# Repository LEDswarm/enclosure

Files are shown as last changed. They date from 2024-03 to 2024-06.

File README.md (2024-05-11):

# `ledswarm_enclosure`

A custom 3D-printed enclosure for LEDswarm controllers, made to be printed out of resin in SLA printers.

This fulfills a similar role as the original bottle blanks used to enclose the electronics of Ghoust controllers, but the design has evolved into a curved transparent enclosure which supports mounting circuit boards and diffusor pipes onto a solid plastic case, holding everything firmly in place, especially regarding the USB-C board-to-board connection between the mainboard and the LED board.

## Features

- Lengthwise PCB slot for a mainboard with board edge (straddle mount) USB-C plug
- Water-tight sealing using flanges with o-rings
- Top surface within the diffusor flange to mount the LED peripheral board with M1.7 screws
- Ceiling projection using a plano-convex lens which is integrated into the top cover

## Links

* (Kameralinsen-mit-stereolithografie-herstellen)[https://formlabs.com/de/blog/kameralinsen-mit-stereolithografie-herstellen/]

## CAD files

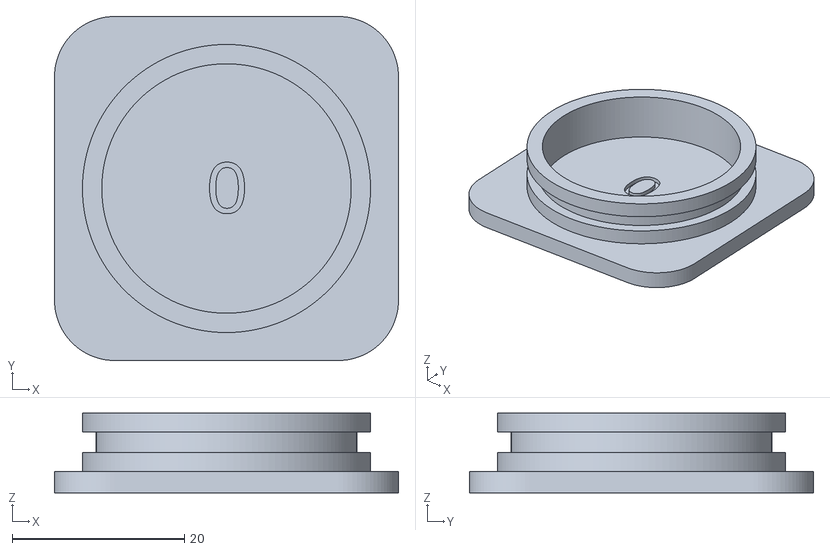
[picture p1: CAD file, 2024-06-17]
o_ring_tester_0.stl
40.0 x 40.0 x 9.25

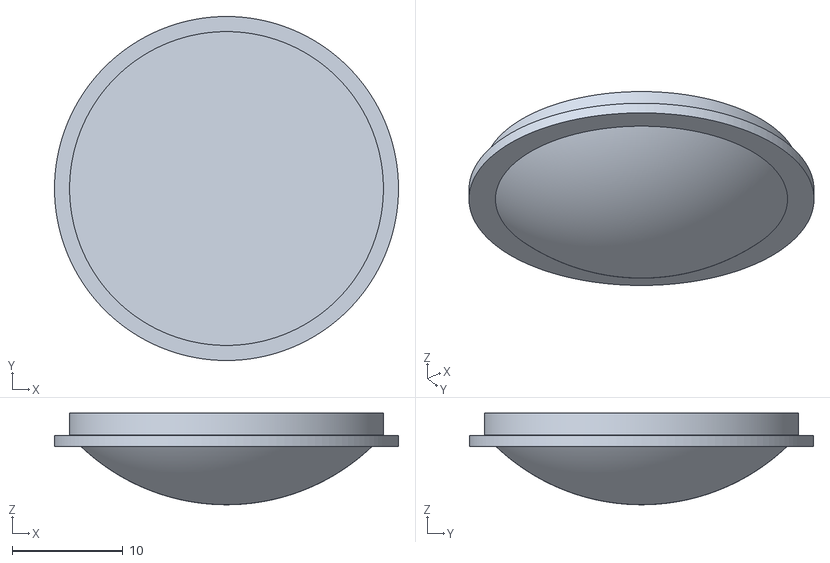
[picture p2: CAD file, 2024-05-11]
stl/top_lens_v1.stl
31.0 x 31.0 x 8.25

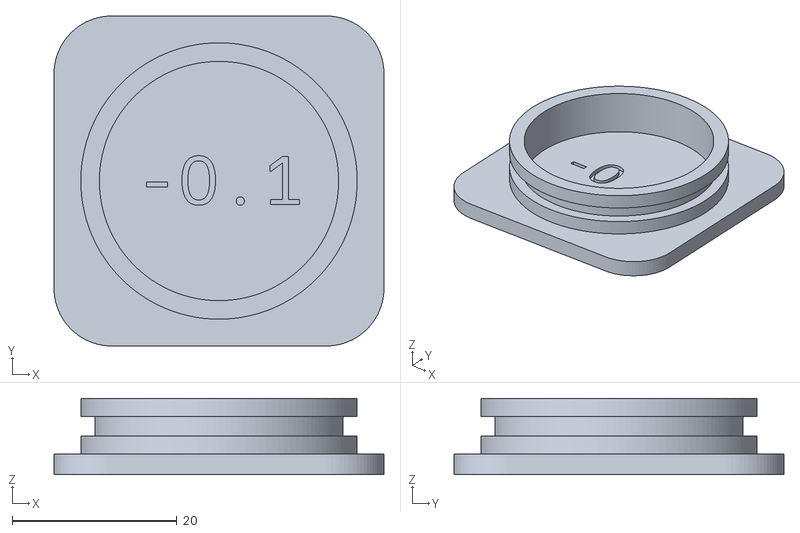
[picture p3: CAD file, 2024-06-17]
o_ring_tester_minus_0_1.stl
40.0 x 40.0 x 9.25

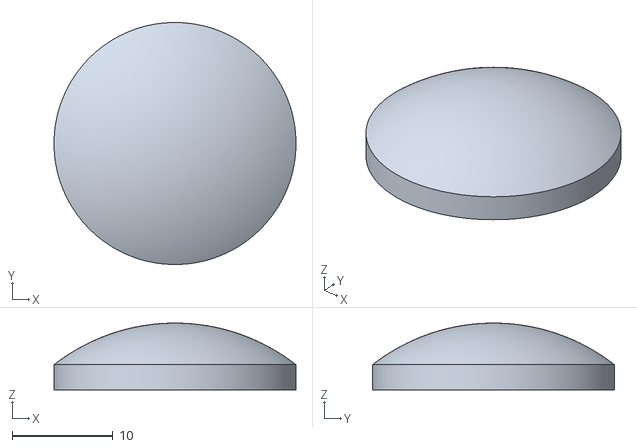
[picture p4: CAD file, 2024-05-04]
lens24mm_2_5.stl
24.0 x 24.0 x 6.63

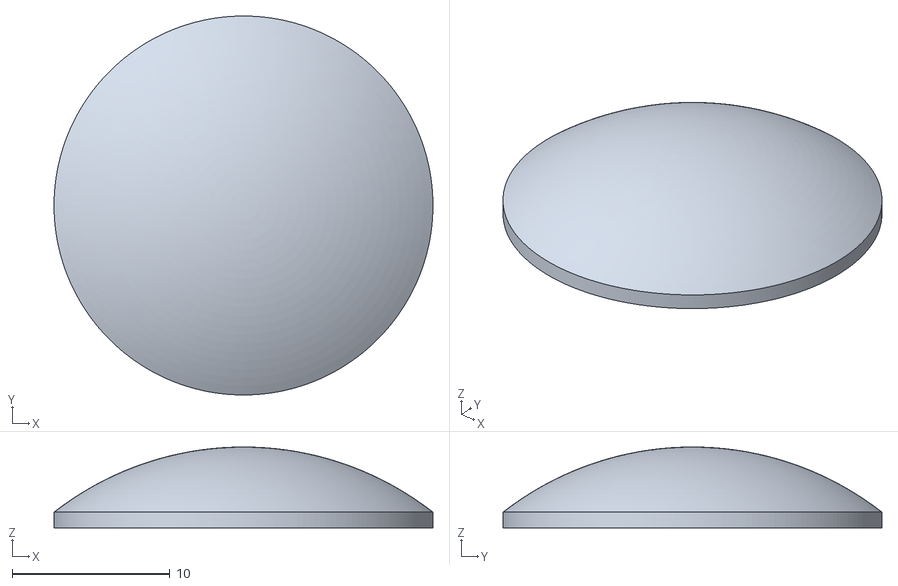
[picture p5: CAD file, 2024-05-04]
lens24mm.stl
24.0 x 24.0 x 5.13

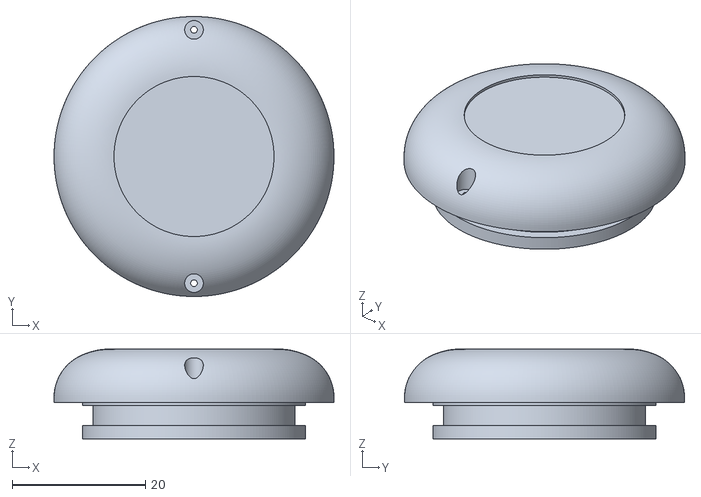
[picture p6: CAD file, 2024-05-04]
top_cover.stl
42.0 x 42.0 x 13.5

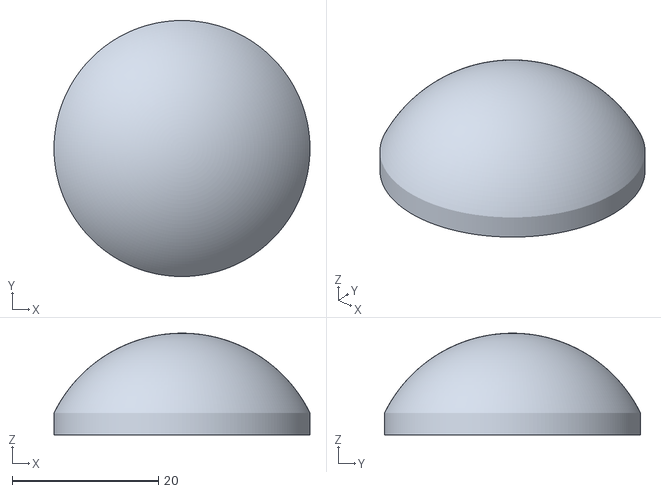
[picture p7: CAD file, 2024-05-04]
lens.stl
35.0 x 35.0 x 13.9

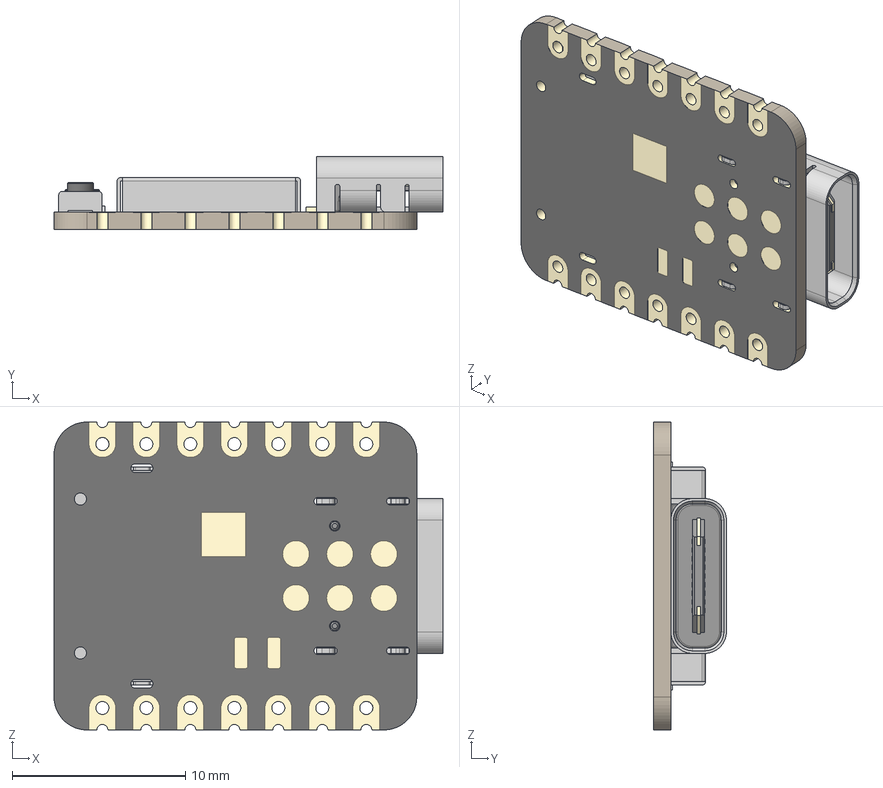
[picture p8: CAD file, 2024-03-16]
esp32c3.step
22.5 x 4.21 x 17.8 mm
BOSS-EXTRUDE14_8_
BOSS-EXTRUDE7_4_
BOSS-EXTRUDE7_3_
BOSS-EXTRUDE14_4_
BOSS-EXTRUDE14_2_
BOSS-EXTRUDE14_11_
BOSS-EXTRUDE7_7_
BOSS-EXTRUDE14_9_
BOSS-EXTRUDE14_3_
BOSS-EXTRUDE14_7_
MIRROR2
BOSS-EXTRUDE14_5_
BOSS-EXTRUDE14_12_
BOSS-EXTRUDE7_8_
BOSS-EXTRUDE7_1_
BOSS-EXTRUDE14_10_
BOSS-EXTRUDE7_9_
BOSS-EXTRUDE14_6_
BOSS-EXTRUDE14_1_
BOSS-EXTRUDE7_6_
BOSS-EXTRUDE7_2_
CUT-EXTRUDE5
BOSS-EXTRUDE7_5_
U.FL Connector v1
Button (1) x 2
Shield

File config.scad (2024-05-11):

pcb_slot_height = 1.8;
pcb_slot_width = 27;
pcb_notch_scale = 0.02485593;

// Default screw length for the LED are 3 millimeters.
led_screw_length = 3.0;
bottom_screw_length = 3.0;

// The height of the controller base in millimeters, not including the LED base and diffusor attachment.
controller_height = 135;
// The radius of the controller base.
controller_radius = 15;
// The height of the LED cylinder.
led_base_height = 10;
// The diameter of the LED cylinder.
led_base_diameter = 23;
// The center of the o-ring can be translated inwards using this variable to adjust the pressure to a functional setting when the diffusor is attached.
led_oring_deepness = 2.0 * 1.35;

controller_mainboard_height_tolerance = 0.5;
controller_mainboard_height = controller_height - controller_mainboard_height_tolerance;

subdivisions = 128;
$fn = subdivisions;

led_screw_diameter = 1.7; // PA Philips Head Micro Screw M1.7
// Ratio for self-cutting plastic screws in brittle SLA printing materials like the ones from JLCPCB.
led_screw_hole_diameter = 0.83 * led_screw_diameter;
// The height of the cylinder below the LED base plate for self-cutting screws to bore into.
led_screw_support_height = 3.0;

top_cover_screw_diameter = 1.7; // PA Philips Head Micro Screw M1.4
top_cover_screw_hole_diameter = 0.83 * top_cover_screw_diameter;
top_cover_screw_support_height = 3.0;

top_plate_cutout_width = 16.2;
top_plate_cutout_height = 10;

module ring(outer_diameter, inner_diameter, height) {
    difference() {
        cylinder(h=height, r=outer_diameter/2);
        translate([0, 0, -5])
        cylinder(h=height + 10, r=inner_diameter/2);
    }
}

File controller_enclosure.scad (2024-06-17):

include <lib/round_anything/polyround.scad>;
include <config.scad>;

include <src/enclosure/base.scad>;
include <src/controller_pcb.scad>;
//include <src/top_lens.scad>;
//include <src/diffusor.scad>;

include <../NeoPixelRing/openscad/board/board.scad>;
include <../NeoPixelRing/openscad/config.scad>;

// LED PCB Mockup
//
//translate([0, 0, 160])
//rotate([0, 0, 90])
//BoardPcb();

color([0.8, 0.8, 0.8])
ControllerPcb();

//TopCover();

// 3mm Wall Thickness Measuring Cube
// translate([0, 16.5, 155])
// color([0.8, 0.8, 0.8])
// cube([3, 3, 3]);


//color([0, 0.5, 0.7])
translate([30, -30, 0])
rotate([90, 0, 90])
scale([0.1, 0.1, 0.1])
linear_extrude(height = 20, center = true, scale=1.0)
import(file = "logo.svg", center = true, dpi = 96);

//translate([0, 0, 0])
//import("./top_cover2.stl", convexity=3);

difference() {
    EnclosureBase();

    translate([
        pcb_slot_height / 2 * (-1),
        pcb_slot_width / 2 * (-1),
        -10,
    ])
    cube([
        pcb_slot_height,
        pcb_slot_width,
        controller_height + 10,
    ]);

    //
    // LED Screw Holes
    //
    translate([0, -led_pcb_screw_hole_center_distance, 155 - 2])
    cylinder(h=6.5, r=led_screw_hole_diameter / 2);

    translate([0, led_pcb_screw_hole_center_distance, 155 - 2])
    cylinder(h=6.5, r=led_screw_hole_diameter / 2);

    // Cut-out so we can look inside
    //translate([-100, -100, -10])
    //cube([200, 200, 130 + 10]);
}

difference() {
    translate([0, -led_pcb_screw_hole_center_distance, 155 - 5.5])
    cylinder(h=4.0, r=led_screw_hole_diameter / 2 + 1);

    translate([0, -led_pcb_screw_hole_center_distance, 155 - 8.5])
    cylinder(h=8.0, r=led_screw_hole_diameter / 2);
}

difference() {
    translate([0, led_pcb_screw_hole_center_distance, 155 - 5.5])
    cylinder(h=4.0, r=led_screw_hole_diameter / 2 + 1);

    translate([0, led_pcb_screw_hole_center_distance, 155 - 8.5])
    cylinder(h=8.0, r=led_screw_hole_diameter / 2);
}

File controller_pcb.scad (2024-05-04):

include <lib/round_anything/polyround.scad>;
include <config.scad>;

$fn=64;

// The width of the PCB in its slot
pcb_width = 26.7;
// The width of the protruding USB-C connector used to connect to the LED.
pcb_arm_width = 14;
pcb_arm_height = 15;
pcb_thickness = 1.0;

usbcPortWidth = 9;
usbcPortHeight = 3.26;
usbcPortDepth = 7.35;
usbcPortWallThickness = 0.3;
usbcPortCenterBlockHeight = 0.6;
usbcPortCenterBlockWidth = 6.0;

xiao_esp32_length = 22.2;
xiao_esp32_width = 17.9;

dwm3000_width = 23.0;

usbcPort();

color([0.8, 0.8, 0.8])
pcb();

module pcb() {
    /// PCB Mockup
    union () {
        translate([0, 0, 0])
        cube([pcb_thickness, pcb_width, 135]);

        translate([0, (pcb_width - pcb_arm_width) / 2, 135])
    cube([pcb_thickness, pcb_arm_width, 15]);
    }
}

module usbcPort() {
    difference() {
        translate([1, (pcb_width - usbcPortWidth) / 2, controller_height + pcb_arm_height - usbcPortDepth])
        color([0.7, 0.7, 0.7])
        linear_extrude(height = usbcPortDepth) polygon(polyRound(usbcProfile(), $fn));

        translate([1, (pcb_width - usbcPortWidth) / 2, controller_height + pcb_arm_height - usbcPortDepth + 1])
        color([0.7, 0.7, 0.7])
        linear_extrude(height = 8) polygon(polyRound(usbcProfileCutout(), $fn));
    }

    translate([pcb_thickness + (usbcPortHeight - usbcPortCenterBlockHeight) / 2, (pcb_width - usbcPortCenterBlockWidth) / 2, controller_height + pcb_arm_height - usbcPortDepth + 1])
    color([0.7, 0.7, 0.7])
    cube([0.6, 6, 6]);

    function usbcProfile(extension=0,edgeRadius=10)=translateRadiiPoints(
        [
        [0, 0, 1],
        [usbcPortHeight, 0, 1],
        [usbcPortHeight, usbcPortWidth, 1],
        [0, usbcPortWidth, 1],
        ],
    [0,0]
    );

    function usbcProfileCutout(extension=0,edgeRadius=10)=translateRadiiPoints(
        [
        [usbcPortWallThickness, usbcPortWallThickness, 0.7],
        [usbcPortHeight - usbcPortWallThickness, usbcPortWallThickness, 0.7],
        [usbcPortHeight - usbcPortWallThickness, usbcPortWidth - usbcPortWallThickness, 0.7],
        [usbcPortWallThickness, usbcPortWidth - usbcPortWallThickness, 0.7],
        ],
    [0,0]
    );
}

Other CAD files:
o_ring_tester_0_1.stl
o_ring_tester_0_2.stl
o_ring_tester_minus_0_2.stl
src/controller_pcb.scad
led_pcb.scad
mcu.scad
o_ring_tester.scad
src/bottom_cover.scad
src/diffusor.scad
src/enclosure/base.scad
src/top_cover.scad
src/top_lens.scad
test.scad

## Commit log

2024-03-16 chore: add lots of things, build LED PCB design
    [config.scad, controller_enclosure.scad, controller_pcb.scad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]
2024-04-27 feat: start working on version 2 of the enclosure
    [base.scad, config.scad, controller_enclosure.scad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]
2024-04-27 chore: clean up a bit
    [base.scad]
2024-04-28 chore: add ghoust logo
    [base.scad, config.scad, controller_enclosure.scad]
2024-05-09 feat: add groove offset
    [base.scad]
2024-05-09 feat: add o-ring tester board
    [o_ring_tester.scad]
2024-05-11 chore: design a system cover which uses a glued lens
    [config.scad, controller_enclosure.scad, top_cover.scad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]
2024-05-11 chore: add lens stl
    [top_lens_v1.stl]
2024-05-11 wip: add half-attached o-ring mount
    [top_cover.scad]
2024-05-25 fix: o-ring groove adjustments
    [base.scad, o_ring_tester.scad, top_cover.scad]
2024-06-16 chore: revert to previous integrated-lens top cover design
    [top_cover.scad]
2024-06-16 chore: remove top cover and hide cutout
    [controller_enclosure.scad]
2024-06-16 chore: set default flange offset to +1.0 (the best fitting o ring tester) and fix typos
    [base.scad]
2024-06-16 chore: add stl renders of o-ring testers and the current glue flange
    [o_ring_tester_0.stl, o_ring_tester_0_1.stl, o_ring_tester_0_2.stl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]
2024-06-17 fix: overlapping inner edge at transition from cylinder to s-curve
    [base.scad]
